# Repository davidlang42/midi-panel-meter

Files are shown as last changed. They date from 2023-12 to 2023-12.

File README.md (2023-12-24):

# midi-panel-meter

A CLI application which reads MIDI_IN and displays current status of pedals and notes on a panel meter.

For instructions on how to run this on a Raspberry Pi 0-2w, click [here](hardware/SETUP.md).

## Development instructions

To modify this code locally on a non-Raspberry Pi architecture linux, you will need to [do the following](https://medium.com/swlh/compiling-rust-for-raspberry-pi-arm-922b55dbb050):
- `sudo apt install gcc-arm-linux-gnueabihf`
- `rustup target add armv7-unknown-linux-gnueabihf`
- `cargo check --target=armv7-unknown-linux-gnueabihf`

Unfortunately building is only possible on the RPi itself due to the LED driver's requirements.

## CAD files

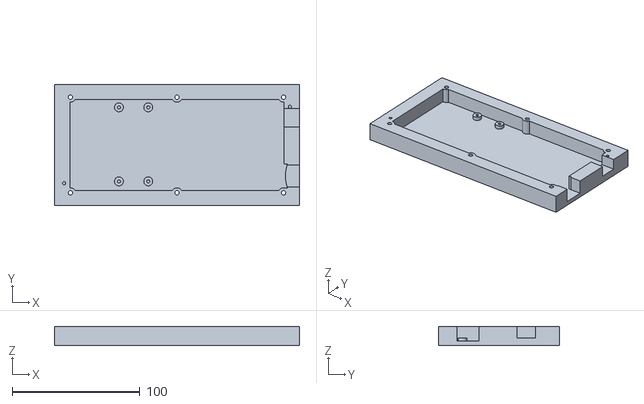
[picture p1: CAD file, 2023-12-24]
hardware/Pi-meter_base_v4.stl
192.0 x 95.0 x 15.0

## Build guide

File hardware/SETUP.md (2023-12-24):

# Hardware setup
A useful way to use midi-panel-meter is running on a Raspberry Pi with an led panel.
The following instructions describe how I set it up, which worked successfully for me but otherwise comes with no guarentees or support.

## Parts required
- [Raspberry Pi 2-0w](https://core-electronics.com.au/raspberry-pi-zero-2-w-wireless.html) (wireless is not nessesary, but helps with setup & configuration)
- [32x16 RGB LED Matrix Panel](https://core-electronics.com.au/32x16-rgb-led-matrix-panel-6mm-pitch.html)
- [Micro USB Cable Male Host to USB OTG](https://www.ebay.com.au/itm/292254916725)
- [Micro USB 2.0 Female To Dual 2 Male Splitter Y](https://www.ebay.com.au/itm/384792640528)
- 16GB+ microSD card ([for example](https://www.jaycar.com.au/32gb-micro-sdxc-class-10-reads-90mb-s-writes-30mb-s/p/XC5016))
- PSU (5V 2A) and USB micro cable
- USB cable to connect to MIDI keyboard as required
- Superglue
- [3d printed base](Pi-meter_base_v4.stl)
- 4x m2.5x4 screws (I used m2.5x5 but I think shorter would have been better)
- 6x m3x16 screws
- (optional) 5V 2A label

## SD card setup
1. On another computer with a microSD card reader, install [Raspberry Pi Imager](https://www.raspberrypi.com/software/)
2. Insert microSD card into reader and run Raspberry Pi Imager
3. Follow instructions to flash microSD card with the following details:
- Raspberry Pi OS (64 bit) Lite (No Desktop)
- Enable SSH
- Set hostname, username (pi) and password
- Set WiFi & timezone details
- Add WiFi configuration of your home network (so you can configure it remotely)

## Assembly instructions
1. Led panel wiring as per: https://github.com/hzeller/rpi-rgb-led-matrix/blob/master/wiring.md

| Label | Led pin* | Rpi pin^ |
|---|---|---|
| R1 | 1 | 23 |
| G1 | 2 | 13 |
| B1 | 3 | 26 |
| | 4 | |
| R2 | 5 | 24 |
| G2 | 6 | 21 |
| B2 | 7 | 19 |
| | 8 | |
| A | 9 | 15 |
| B | 10 | 16 |
| C | 11 | 18 |
| | 12 | |
| CLK | 13 | 11 |
| STB | 14 | 7 |
| OE | 15 | 12 |
| GND | 16 | 6 |

- *Pin 1 (top of ribbon) in top right looking at female header with notch on right, ribbon to the right
- ^Pin 1 (square) in top left looking at top of board with sd card up and gpio right

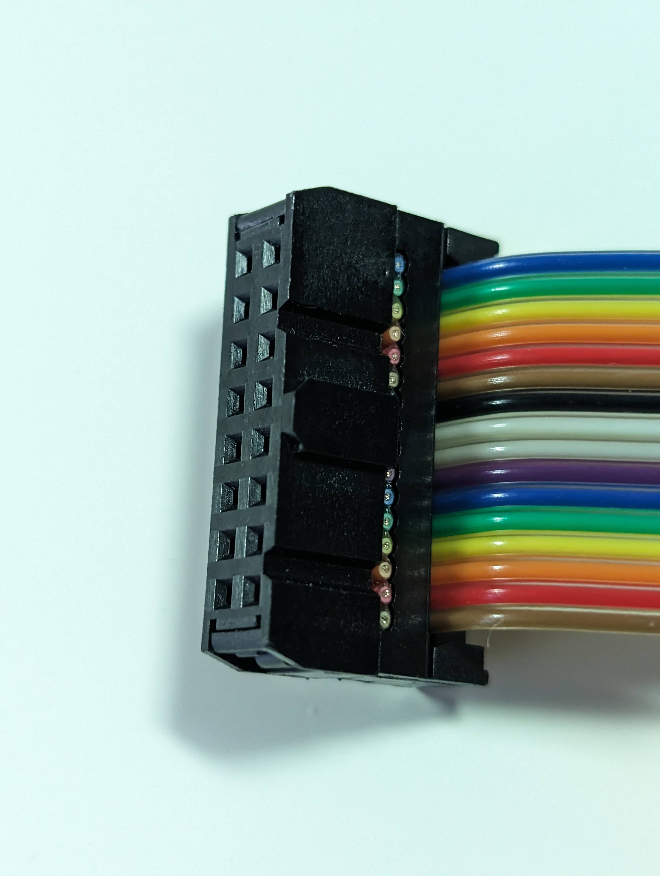
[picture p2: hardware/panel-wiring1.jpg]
panel-wiring1

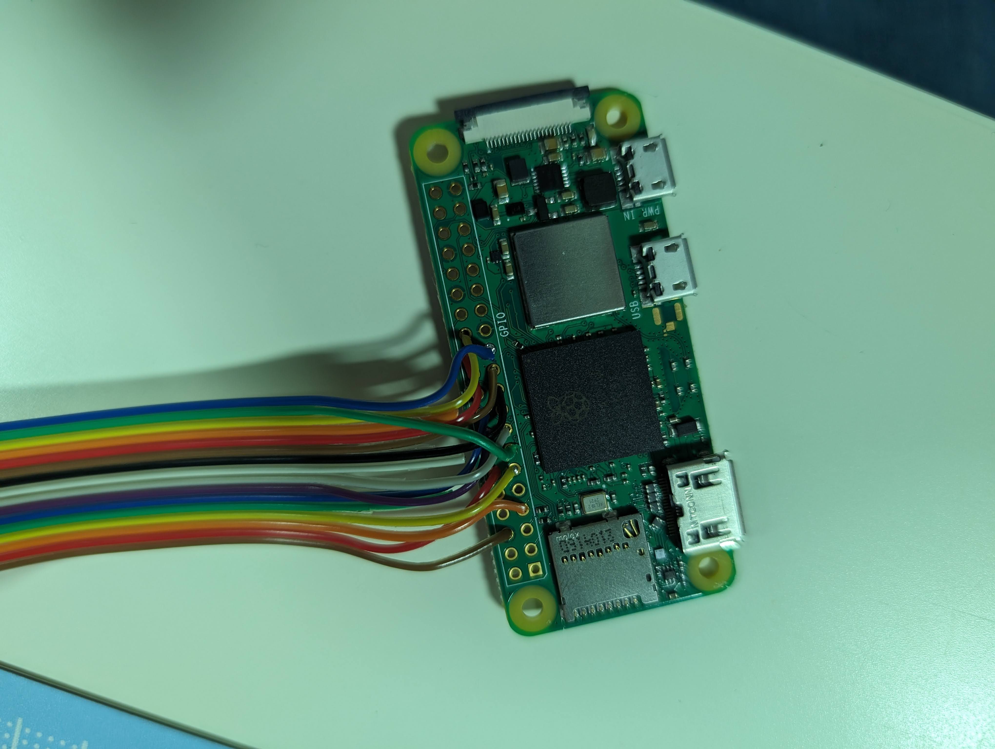
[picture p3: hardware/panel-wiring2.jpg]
panel-wiring2

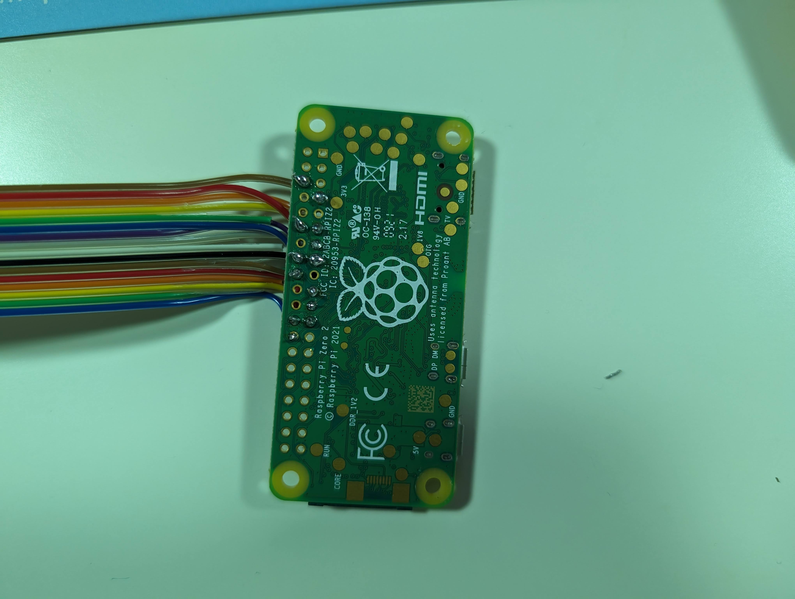
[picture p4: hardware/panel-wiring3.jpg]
panel-wiring3

2. Cut one of the 2 plugs off the usb micro Y splitter, and solder to panel wires (heatshrink and electrical tape recommended)
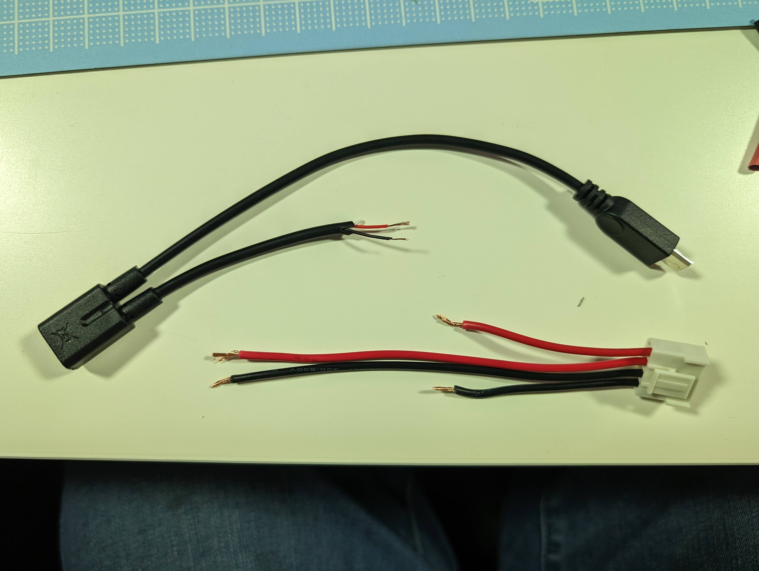
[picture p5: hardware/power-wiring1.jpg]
power-wiring1

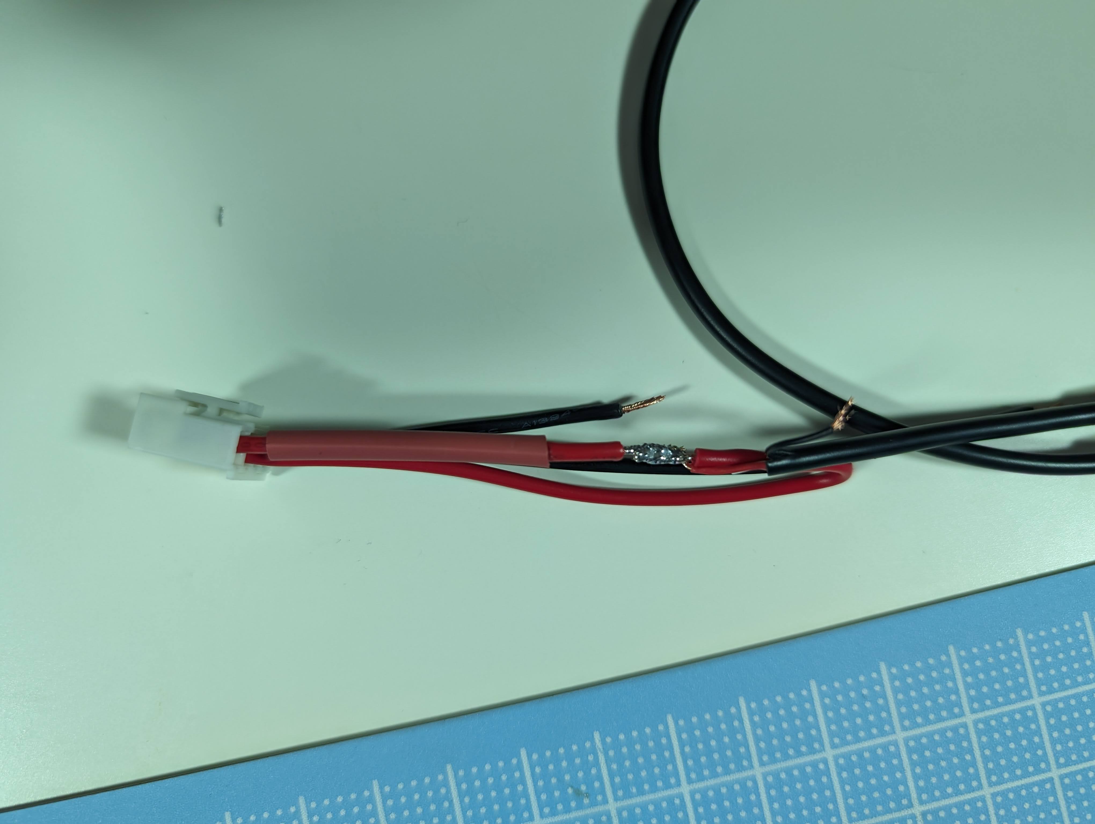
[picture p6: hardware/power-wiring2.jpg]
power-wiring2

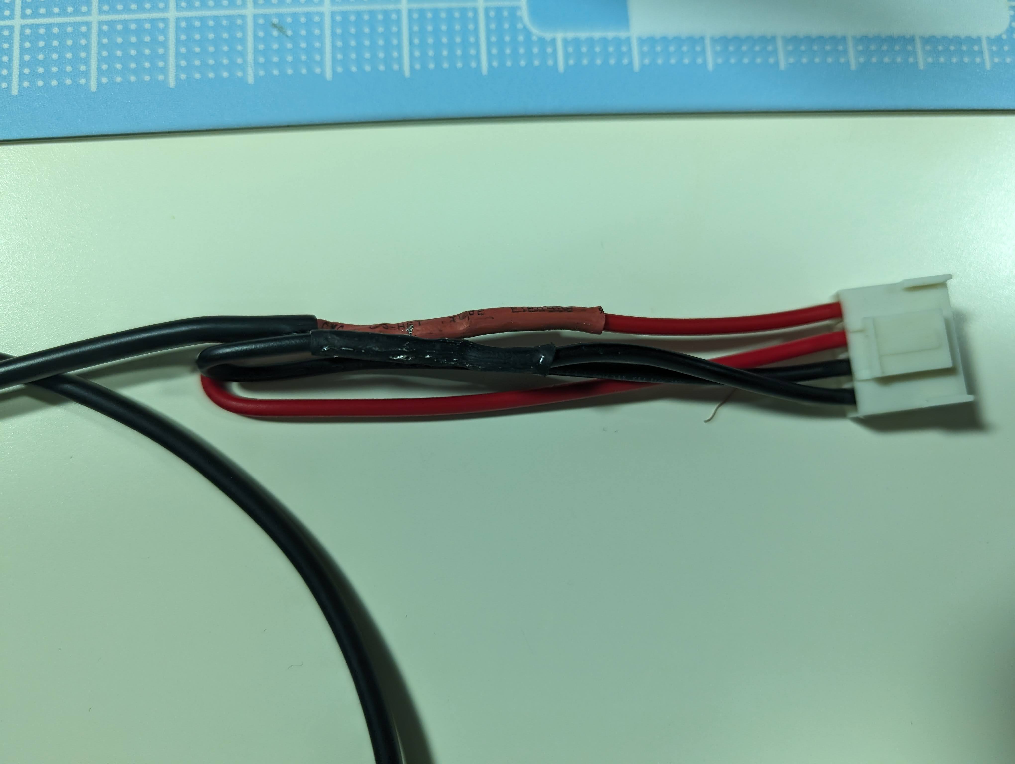
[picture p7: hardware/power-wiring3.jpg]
power-wiring3

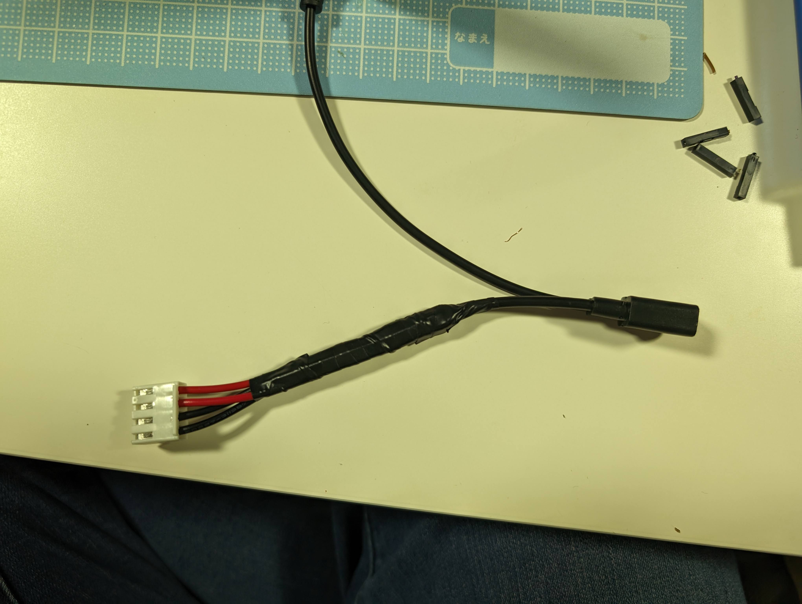
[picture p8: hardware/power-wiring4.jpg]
power-wiring4

3. Insert SD card into RPi
4. Use 4x m2.5x4 screws to screw RPi into base
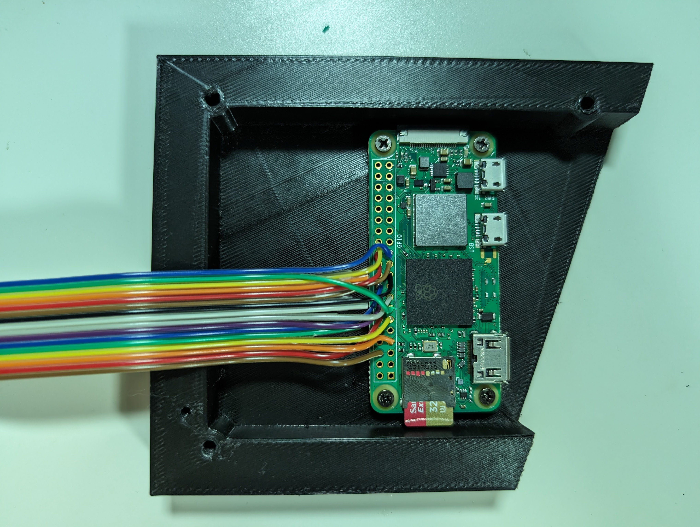
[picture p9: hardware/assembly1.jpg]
assembly1

5. Superglue usb ports into base
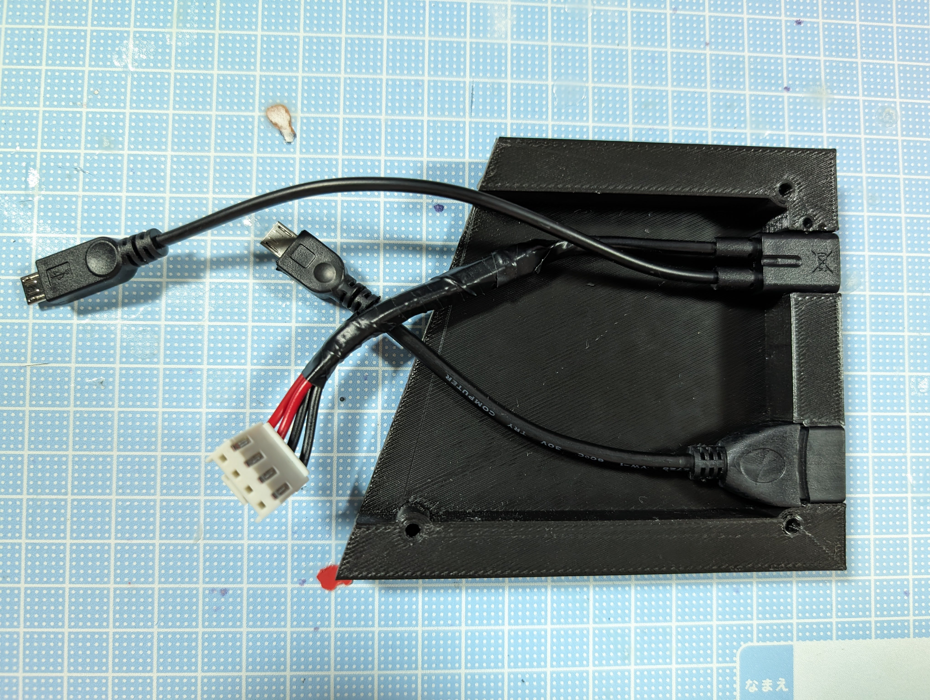
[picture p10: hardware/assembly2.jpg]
assembly2

6. Connect 2x micro usb to RPi (usb-A -> data, usb-micro -> power) and ribbon cable & power to panel
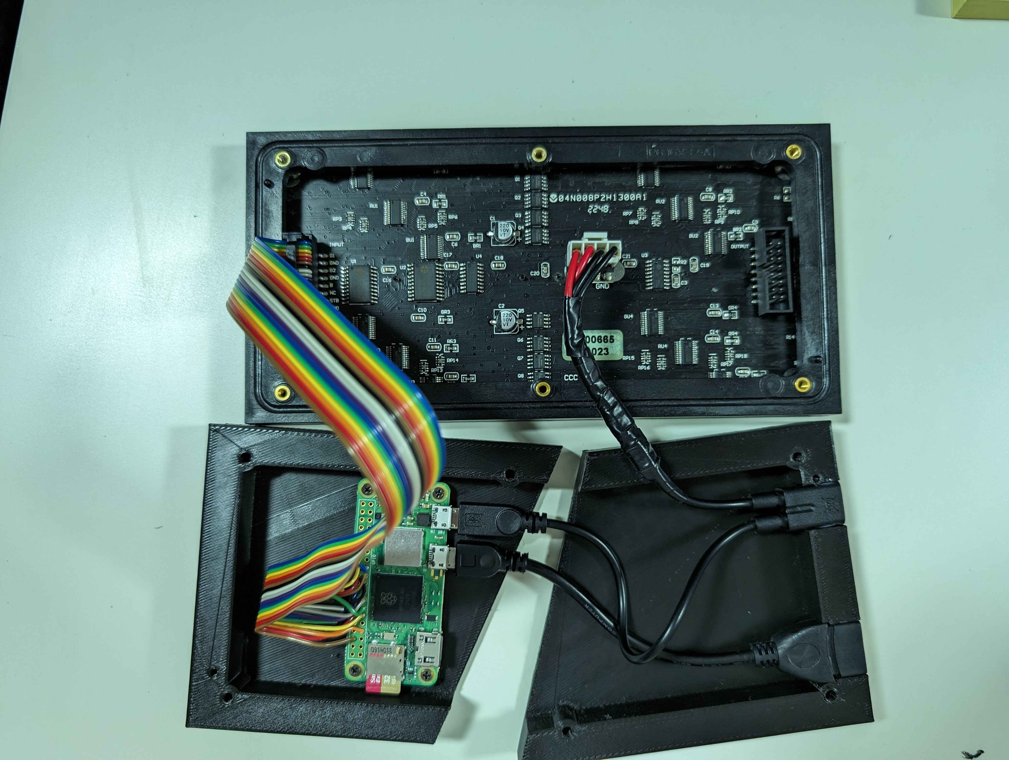
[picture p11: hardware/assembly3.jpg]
assembly3

7. Use 6x m3x16 screws to screw base to panel
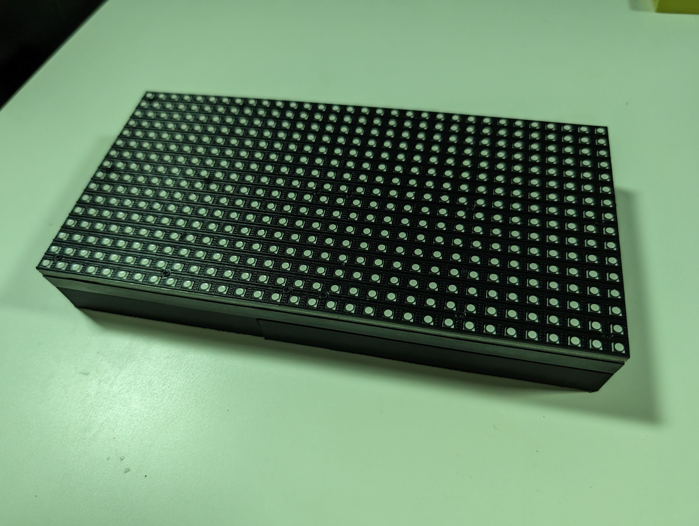
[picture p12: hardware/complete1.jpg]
complete1

8. (optional) Stick 5V 2A label to base
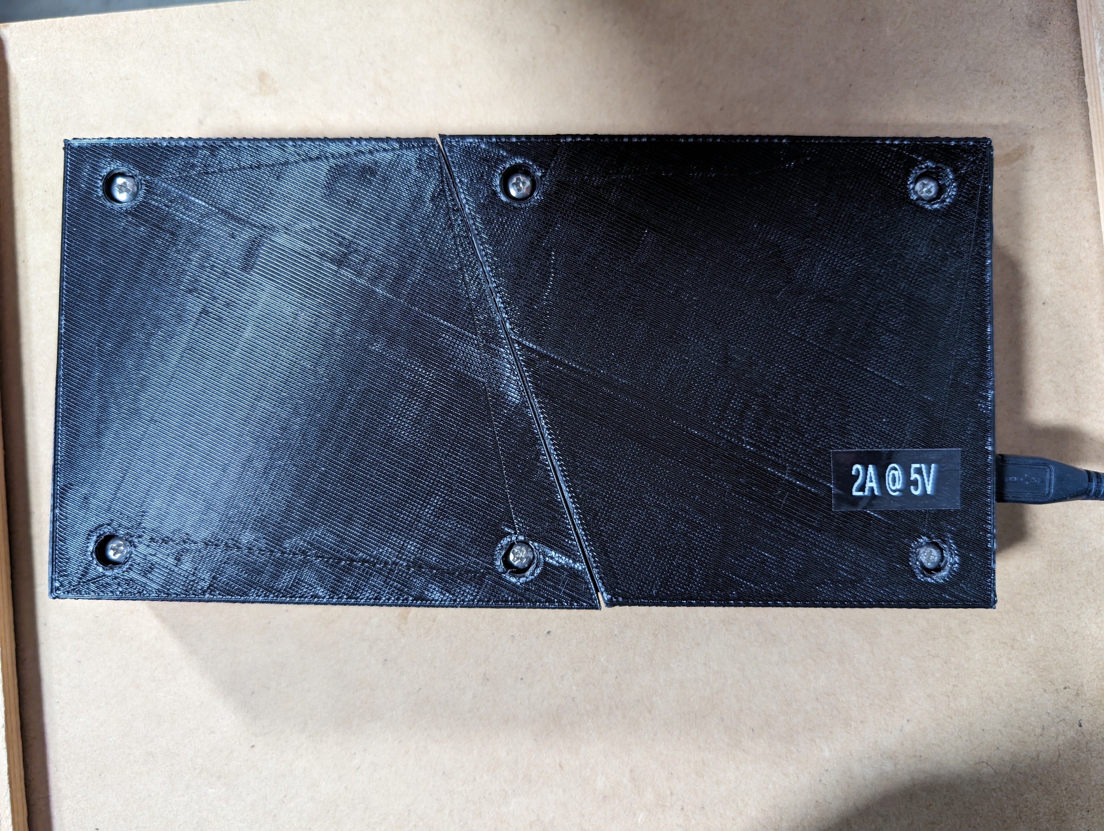
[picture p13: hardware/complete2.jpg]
complete2

9. Plug in PSU, USB keyboard and turn Raspberry Pi on
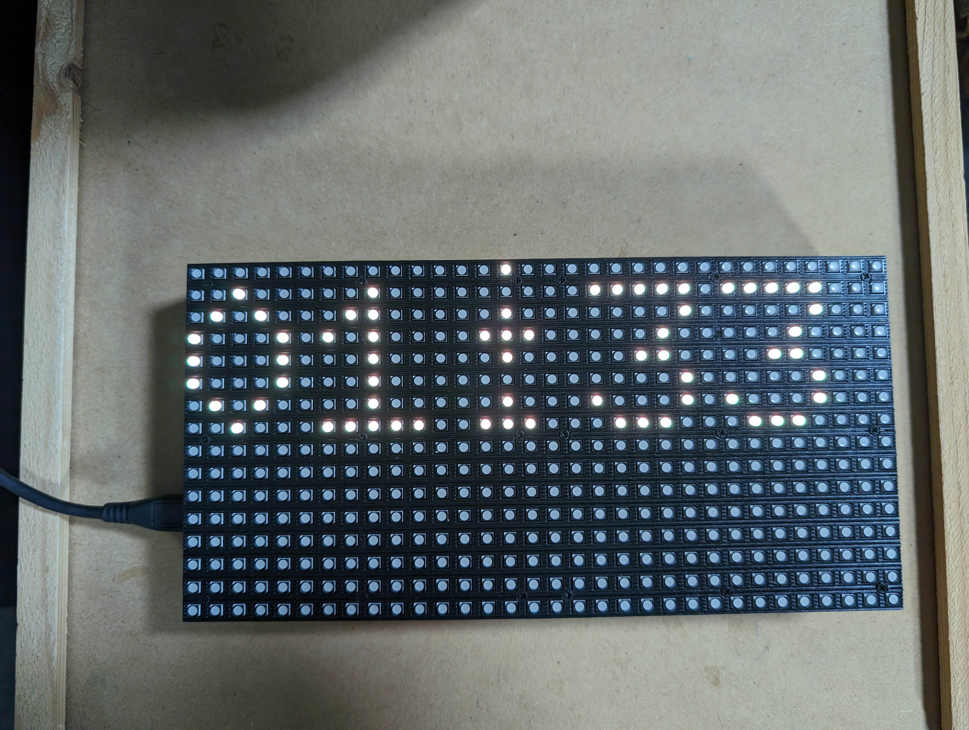
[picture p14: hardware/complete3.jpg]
complete3


## Software configuration
1. Once the Raspberry Pi has turned on and booted up, it should connect to the WiFi network you configured above, confirm this using `ping HOSTNAME`
2. Use Putty or SSH in terminal to SSH into the raspberry pi using the username and password you configured above
3. Increase swap so that [rust will install](https://gist.github.com/tstellanova/0a6d8a70acc58a0d5be13ebaa7c935d4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)
- `sudo dphys-swapfile swapoff`
- `sudo nano /etc/dphys-swapfile`
- Change CONF_SWAPSIZE=100 to CONF_SWAPSIZE=512
- Save & exit
- `sudo dphys-swapfile setup`
- `sudo dphys-swapfile swapon`
4. Install rust `curl https://sh.rustup.rs -sSf | sh`
5. Configure other WiFi networks if required `sudo nano /etc/wpa_supplicant/wpa_supplicant.conf`
6. Disable sound (because it breaks the LED driver)
- `sudo nano /boot/config.txt`
- Remove: dtparam=audio=on
- Add: dtparam=audio=off
- Save & exit
- `sudo nano /boot/cmdline.txt`
- Add:  isolcpus=3
- Save & exit
- Run this:
```
cat <<EOF | sudo tee /etc/modprobe.d/blacklist-rgb-matrix.conf
blacklist snd_bcm2835
EOF
```
- `sudo update-initramfs -u`
- `sudo reboot`
7. Reconnect to SSH
8. Install git `sudo apt update && sudo apt upgrade && sudo install git`
9. Test hardware with LED driver
- `git clone https://github.com/hzeller/rpi-rgb-led-matrix.git`
- `cd rpi-rgb-led-matrix`
- `make -C examples-api-use`
- `sudo examples-api-use/demo -D0`
- `cd ~`
10. Download code `git clone https://github.com/davidlang42/midi-panel-meter.git`
11. Build code `cd midi-arpeggiator && cargo build --release`
12. Fix permission issue with sudo `sudo groupmod -aU root audio`
13. Make a startup script:
- `nano ~/run_on_startup`
- Type this into nano:
```
#!/usr/bin/bash
cd /home/pi/midi-panel-meter # must be in this dir to find 6x9.bdf
sudo ./target/release/midi-panel-meter # sudo to enable raw memory access for the led driver
```
- Ctrl+X to exit nano (and save)
- `chmod a+x ~/run_on_startup`
14. Make auto shutdown if overheat script"
- `nano ~/shutdown_on_temp`
- Type this into nano:
```
#!/usr/bin/bash
set -e
MAX="80"
while [ true ]
do
    SENSOR="`vcgencmd measure_temp | cut -d "=" -f2 | cut -d "'" -f1`"
    TEMP="`printf "%.0f\n" ${SENSOR}`"
    if [ "${TEMP}" -gt "${MAX}" ]
    then
        /usr/bin/logger "Shutting down due to cpu temp ${TEMP}."
        sudo shutdown -h now
    fi
    sleep 60
done
```
- Ctrl+X to exit nano (and save)
- `chmod a+x ~/shutdown_on_temp`
15. Make the scripts run on startup:
- `sudo nano /etc/rc.local`
- Append these lines before the last line:
```
/home/pi/run_on_startup &
/home/pi/shutdown_on_temp &
```
- Ctrl+X to exit nano (and save)
16. Reboot to make the panel meter run `sudo reboot`
17. Enjoy your Raspberry Pi MIDI panel meter!
- If you have any suggested improvements, raise an [issue](https://github.com/davidlang42/midi-panel-meter/issues) or submit a [pull request](https://github.com/davidlang42/midi-panel-meter/pulls)
- If you find this useful, consider [buying me a coffee](https://ko-fi.com/davidlang42)

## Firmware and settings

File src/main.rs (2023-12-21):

mod notes;
mod meter;
mod midi;
mod helper;

use meter::PanelMeter;
use midi::NonBlockingInputDevice;
use rpi_led_matrix::LedCanvas;
use rpi_led_matrix::{LedMatrix, LedColor, LedFont, LedMatrixOptions};
use chrono::Local;
use std::path::Path;
use std::time::Duration;
use std::thread;
use std::fs;
use std::error::Error;
use std::time::Instant;

const CLOCK_UPDATE_MS: u128 = 1000;
const METER_UPDATE_MS: u128 = 10; //100Hz

fn main() {
    // set up screen
    let mut options = LedMatrixOptions::new();
    options.set_rows(16);
    options.set_cols(32);
    let matrix = LedMatrix::new(Some(options), None).unwrap();
    // draw clock while waiting for midi
    let mut canvas = matrix.offscreen_canvas();
    let font_path = Path::new("6x9.bdf");
    let font = LedFont::new(&font_path).unwrap();
    let color = LedColor { red: 255, green: 255, blue: 255 };
    let mut colon = true;
    loop {
        let updated = Instant::now();
        let time = if colon {
            colon = false;
            format!("{}", Local::now().format("%H:%M"))
        } else  {
            colon = true;
            format!("{}", Local::now().format("%H %M"))
        };
        canvas.clear();
        canvas.draw_text(&font, &time, 1, 11, &color, 0, false);
        canvas = matrix.swap(canvas);
        if let Some(device) = list_files("/dev", "midi").unwrap().into_iter().next() {
            match NonBlockingInputDevice::open(&device, true) {
                Ok(midi) => canvas = show_midi_panel(midi, canvas, &matrix),
                Err(err) => println!("Error opening MIDI device: {}", err) // Permission denied (os error 13) when running with sudo, unless root is added to 'audio' group
            }
        }
        let ms = updated.elapsed().as_millis();
        if ms < CLOCK_UPDATE_MS {
            thread::sleep(Duration::from_millis((CLOCK_UPDATE_MS - ms).try_into().unwrap()));
        }
    }
}

fn list_files(root: &str, prefix: &str) -> Result<Vec<String>, Box<dyn Error>> {
    let md = fs::metadata(root)?;
    if md.is_dir() {
        let mut files = Vec::new();
        for entry in fs::read_dir(root)? {
            let path = entry?.path();
            if !path.is_dir() && path.file_name().unwrap().to_string_lossy().starts_with(prefix) {
                files.push(path.display().to_string());
            }
        }
        files.sort();
        Ok(files)
    } else {
        Ok(vec![root.to_string()])
    }
}

fn show_midi_panel(mut midi: NonBlockingInputDevice, mut canvas: LedCanvas, matrix: &LedMatrix) -> LedCanvas {
    let mut panel = PanelMeter::new();
    panel.draw(&mut canvas);
    canvas = matrix.swap(canvas);
    while midi.is_connected() {
        let updated = Instant::now();
        let mut changed = false;
        while let Some(message) = match midi.read() {
            Ok(opt) => opt,
            Err(err) => {
                println!("Error reading MIDI device: {}", err);
                return canvas;
            }
        } {
            panel.handle(message);
            changed = true;
        }
        if changed {
            panel.draw(&mut canvas);
            canvas = matrix.swap(canvas);
        }
        let ms = updated.elapsed().as_millis();
        if ms < METER_UPDATE_MS {
            thread::sleep(Duration::from_millis((METER_UPDATE_MS - ms).try_into().unwrap()));
        }
    }
    canvas
}

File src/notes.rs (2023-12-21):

use std::collections::HashMap;

use rpi_led_matrix::{LedCanvas, LedColor};
use wmidi::{Note, Velocity, Channel, U7};

use crate::helper::{add_assign, scale};

#[derive(Debug)]
pub struct NoteSlot<const C: usize> {
    pub note: Note,
    pub channels: [Velocity; C]
}

#[derive(Copy, Clone, Eq, PartialEq)]
enum Direction {
    None, Up, Down
}

impl<const C: usize> NoteSlot<C> {
    pub fn new(n: Note) -> Self {
        Self {
            note: n,
            channels: [U7::MIN; C]
        }
    }

    const BLANK: LedColor = LedColor { red: 0, green: 0, blue: 0 };

    pub fn draw(&self, canvas: &mut LedCanvas, x: i32, colors: &[LedColor; C]) {
        let mut full_pixels = [0; C];
        let mut last_pixel = [0; C];
        for i in 0..C {
            let v: u8 = self.channels[i].into();
            full_pixels[i] = v as usize / 8;
            last_pixel[i] = v % 8 * 32;
        }
        for led in 0..16 {
            let scales = Self::scales(led, &full_pixels, &last_pixel);
            let mut color: LedColor = Self::BLANK;
            for i in 0..C {
                if scales[i] > 0 {
                    if scales[i] < 255 {
                        add_assign(&mut color, &scale(&colors[i], scales[i]));
                    } else {
                        add_assign(&mut color, &colors[i]);
                    }
                }
            }
            canvas.set(x, 15 - led as i32, &color);
        }
    }

    fn scales(led: usize, full_pixels: &[usize; C], last_pixel: &[u8; C]) -> [u8; C] {
        let mut scales = [0; C];
        for i in 0..C {
            scales[i] = if led < full_pixels[i] {
                255
            } else if led == full_pixels[i] {
                last_pixel[i]
            } else {
                0
            };
        }
        scales
    }

    pub fn is_empty(&self) -> bool {
        self.channels.iter().all(|v| *v == U7::MIN)
    }
}

pub struct NoteSlots<'a, const N: usize, const C: usize> {
    slots: [Option<NoteSlot<C>>; N],
    colors: &'a [LedColor; C],
    damper: [bool; C],
    when_damper_released: [HashMap<Note, Velocity>; C]
}

impl<'a, const N: usize, const C: usize> NoteSlots<'a, N, C> {
    pub fn new(colors: &'a [LedColor; C]) -> Self {
        let mut slots = Vec::new();
        for _ in 0..N {
            slots.push(None);
        }
        let mut when_damper_released = Vec::new();
        for _ in 0..C {
            when_damper_released.push(HashMap::new());
        }
        Self {
            slots: slots.try_into().unwrap(),
            colors,
            damper: [false; C],
            when_damper_released: when_damper_released.try_into().unwrap()
        }
    }

    pub fn draw(&self, canvas: &mut LedCanvas, first_column: i32) {
        for s in 0..N {
            if let Some(slot) = &self.slots[s] {
                slot.draw(canvas, first_column + s as i32, self.colors);
            }
        }
    }

    pub fn set_channel(&mut self, ch: Channel, v: Velocity) {
        let c = ch.index() as usize;
        if c < C {
            for s in 0..N {
                let mut delete = false;
                if let Some(slot) = &mut self.slots[s] {
                    if slot.channels[c] > U7::MIN {
                        slot.channels[c] = v;
                        delete = slot.is_empty();
                    }
                }
                if delete {
                    self.slots[s] = None;
                }
            }
        }
    }

    pub fn set_damper(&mut self, ch: Channel, damper: bool) {
        let c = ch.index() as usize;
        if c < C {
            self.damper[c] = damper;
            if !damper {
                let vec: Vec<_> = self.when_damper_released[c].drain().collect();
                for (n, v) in vec {
                    self.process_note(n, c, v, false);
                }
            }
        }
    }

    const MIN_NOTE: Note = Note::A0;
    const MAX_NOTE: Note = Note::C8;

    pub fn set_note(&mut self, n: Note, ch: Channel, v: Velocity) {
        let c = ch.index() as usize;
        if c < C && n >= Self::MIN_NOTE && n <= Self::MAX_NOTE {
            if self.damper[c] {
                if v == U7::MIN {
                    // delay note off until damper released
                    self.when_damper_released[c].insert(n, v);
                } else {
                    // keep only the last press when damper released
                    self.when_damper_released[c].insert(n, v);
                    // but show the sum of them now
                    self.process_note(n, c, v, true);
                }
            } else {
                // show the note as is
                self.process_note(n, c, v, false);
            }
        }
    }

    fn process_note(&mut self, n: Note, c: usize, mut v: Velocity, sum_existing_v: bool) {
        let s = if let Some(existing) = self.find_slot(n) {
            // if note already exists, use that slot
            if sum_existing_v {
                let v_u8: u8 = v.into();
                let existing_u8: u8 = self.slots[existing].as_ref().unwrap().channels[c].into();
                let sum = v_u8 + existing_u8;
                v = if sum >= U7::MAX.into() {
                    U7::MAX
                } else {
                    U7::from_u8_lossy(sum)
                }
            }
            existing
        } else {
            // find ideal slot by scaling all 88 piano notes into the number of slots
            let ideal = (N * (n as usize - Self::MIN_NOTE as usize)) / (Self::MAX_NOTE as usize - Self::MIN_NOTE as usize + 1);
            // move the ideal to be valid compared to other notes already existing
            let valid = self.valid_relative_to_existing(ideal, n);
            // create a slot for this note (moving others if nessesary)
            let index = self.make_free_slot(n, valid, Direction::None);
            self.slots[index] = Some(NoteSlot::new(n));
            index
        };
        // update slot
        self.slots[s].as_mut().unwrap().channels[c] = v;
        if self.slots[s].as_ref().unwrap().is_empty() {
            self.slots[s] = None;
        }
    }

    fn valid_relative_to_existing(&self, ideal: usize, n: Note) -> usize {
        let mut valid = None;
        for i in (ideal + 1)..N {
            if let Some(slot) = &self.slots[i] {
                if slot.note < n {
                    valid = Some(i);
                } else if slot.note > n {
                    break;
                }
            }
        }
        if let Some(v) = valid {
            return v;
        }
        for i in (0..ideal).rev() {
            if let Some(slot) = &self.slots[i] {
                if slot.note > n {
                    valid = Some(i);
                } else if slot.note < n {
                    break;
                }
            }
        }
        if let Some(v) = valid {
            return v;
        }
        ideal
    }
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

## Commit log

2023-11-15 Add setup notes and example code
    [Pi-meter pinout.xlsx]
2023-11-15 Add rough case design
2023-12-19 Fix some compile errors
    [panel_meter.rs]
2023-12-20 Make free slot, TODOs in code
2023-12-21 Set refresh rate to 100Hz
2023-12-21 Make sure new slot is a valid location
2023-12-24 Add hardware setup notes
    [Pi-meter_base_v4.stl]
2023-12-24 Clean up extra files
    [Pi-meter pinout.xlsx]
